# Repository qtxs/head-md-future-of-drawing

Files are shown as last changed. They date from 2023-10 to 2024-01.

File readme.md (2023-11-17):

# Work in progess. Future of drawing

John is a portatif assitant, a guide for beginer students on their artistic journey. He translates their daily movements into graphic poems, using the taken paths as the graphic layout. At the moments when user feels inspired and lost, John prints out a poem that aimed to trigger inspiration. I want to make young artists understand that very simple gestures, even mouvement is already an art from. Much like their artistic path and development, its the process that counts the most, not the final output. 

More stuff [here](/process/)

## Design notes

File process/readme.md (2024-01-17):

# Steps to build the thing 

07.12.2023

## Form
- 3D Modeling 
    - Case
        - Inside box for electronics
        - The main "pencil case" shape in two separate parts
        - Slider 

## Materials
- 3D Printing 
    - Box for electronics
    - The slider 
- Metal 
    - "Pencil case" part one - cut and bend
    - "Pencil case" part two - cut and bend
- Fasterners 
    - Probably couple of screws

## Electronics

- Arduino
    - Code
        - GPS tracker
        - Use gps data for text paths
        - Poem library
        - Light censor to trigger print
        - Thermal Printer control
    - Inputs
        - GPS
        - Light sensor
    - Output
        - Printer
- Dimensions
    - GPS tracker : (not including coin cell or holder):  
    - Printer : with seat 82 x 58 x 44mm / without seat 77 x 53 x 42mm
    - Light sensor: 40 x 16 x 7 mm
- Wiring 
    - What is connected to what 
- Power
    - Serie of lipos 
        - 100.5 x 48.5 x 18mm
        - 5V 3A / 3V 1A

##

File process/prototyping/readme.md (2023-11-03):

# Prototyping. Work in progesss.

The departure point for those prototypes was an idea of creating a portable ai assistant that would capture mouvements, gps paths and other stuff (to define still but probs weather too) and translate them into a visual poem. I aim to create an annoying assitant that would capture the lack of mouvement and on that point it would print out a ticket saying that it's time to get shit done. The paths made by the user before he/she sits for too long, are used as paths for the printed poems.

So while making those prototypes, I tried out three variants, depending on its portability and possible interactions. I should also mention that as my goal is to translate common daily rituals/mouvements all types of interactions are not direct so I didn't find it convinient to test the interaction part on other people.

So there are my observations:

# Prototype 1

Prototype 01 was inspired by my portable iphone case. I often use it myself for writing down my random thoughts during the day etc.

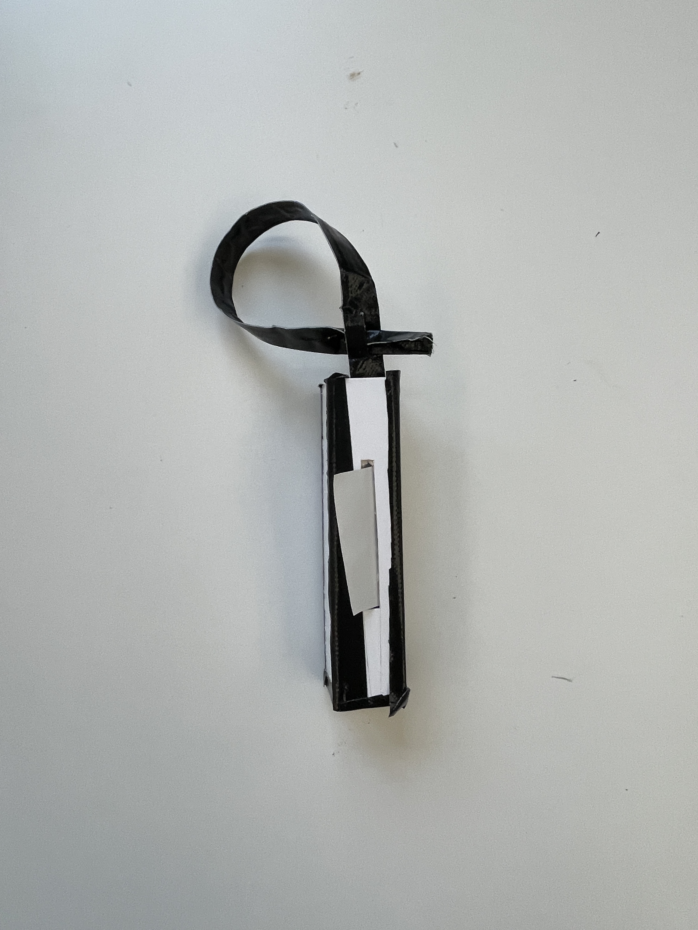
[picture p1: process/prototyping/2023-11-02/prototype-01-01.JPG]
Reference Image

Reference Image

## -
    As I want to integrate a small printer inside of it, it's going to be way too heavy
    Annoying object on the hand
    Not so pratical 
    Not so pretty 

## +
    Possible to integrate other sensors like body temeorature, hand lifting, haertbeat frequency

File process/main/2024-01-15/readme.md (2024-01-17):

# Electronics

15.01.2024

I didn't manage to make my old code workable. So I prepared a serie of [bitmaps](/process/main/2024-01-15/Bitmaps/poems//) compositions that I made, using the haikus that I generated with chat gpt. The went out pretty well but I still encountered some issues with color intensity. I guess it's just the heating issues as with each print it became darker.
[Refence Image](/process/main/2024-01-15/20240115_Print0.jpeg)
[Refence Image](/process/main/2024-01-15/20240115_Print1.jpeg)
[Refence Image](/process/main/2024-01-15/20240115_Print2.jpeg)
[Refence Image](/process/main/2024-01-15/20240115_Print3.jpeg)
[Refence Image](/process/main/2024-01-15/20240115_Print4.jpeg)

Wasn't expecting that bitmaps would require so much memory, so for the demo I can only use one of them. I wanted to print a random one each time it's on, but it's to big. It was also the biggest size that I found 384x550 px and it still looks small though.

The rest of the day I spent on the final [documentation](/process/presentations/20241112_HEAD-MD1_Caran-d-Ache_Ekaterina-Bliznyuk_John.pdf) and made some nice rendredings:
[Reference Image](/process/main/2024-01-15/side01.png)
[Reference Image](/process/main/2024-01-15/front01.png)
[Reference Image](/process/main/2024-01-15/front03.png)

I also found this [thing](/process/main/2024-01-15/2.stl) on web, to use as a clipper for my prints.

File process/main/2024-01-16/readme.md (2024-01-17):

# Finalising

16.01.2024

By today everything was 99% ready. Just needed to polish the rest of objects, put them together, make cable management, try out demo etc.
[!Reference Image](/process/main/2024-01-16/20240116_Nerding.JPG)

I also printed out a cover for the hole that I had to make on my printer.
[!Reference Image](/process/main/2024-01-16/20240116_CoverFront.png)
[!Reference Image](/process/main/2024-01-16/20240116_CoverBack.png)

I also made some slight adjustements on my [code](/process/electronics/printer/Final/FinalCode/FinalCode.ino)
The final of my [fusion](/process/main/2024-01-16/Ekaterina_Bliznyuk_Final.f3d)

I had some free time afterwards, so I made [slides](/process/presentations/20241712_Slides.pdf) for the jury presenation.

So I guess this is the end. Was a cool project, thank you!

[!Reference Image](/process/main/2024-01-16/20240116_ThankYou.gif)

P.S. would like to know how it goes the grade goes with abscences. I know I had a lot of them but they are all suppossed to be justified (or at least 80%).

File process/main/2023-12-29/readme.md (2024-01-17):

# Electronics

29.12.2023

Testing out printer.
[code](/process/electronics/printer/)

There is the [docuement](/process/main/2023-12-29/CommandsSet.pdf) I was using, found in DFRobot. Test pics are [here](/process/main/2023-12-29/)

 Different layots, type rotation etc. For now I just added a random number to define the printing left margin, but with gps I will map those values. Images of tests are in the folder. Goig out pretty well, need to decide which one I prefere esthetically and which works the most with gps data.

 Still need to change the font, which will be more tricky as I need to convert each character to bitmap image and associate it to the letters. Seems doable.

 Next steps:

1. Change font
2. Make list of poems to randomly compose them
3. Use gps data
4. Finish 3d model and print it at home

Here are the correct schemes of my connections.
[!Reference Image](/process/main/2023-12-29/20231229_Scheme01.png)
[!Reference Image](/process/main/2023-12-29/20231229_Scheme02.png)

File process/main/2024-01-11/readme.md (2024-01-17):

# Form

 11.12.2024

Went back to Xavier with the all the pieces. He was quite unhappy as I actually did it wrong and print supports in PLA and not carbon, they were too empty and not restant enough. But it still somehow worked #feelingblessed.

All other part of the day was working on [documentation](/process/presentations/20241112_HEAD-MD1_Caran-d-Ache_Ekaterina-Bliznyuk_John.pdf).

Sadly tho, because I had some questions to Piere but he wasn't here.

Fun fact, any of my electronics haven't arrived yet. Hopping for tomorrow as it will infleunce a lot my demo.

Next steps:

1. Polish metal
2. Print second part
3. Improve code
4. Get that printer

How polishing goes so far:

[Reference Image](/process/main/2024-12-11/20241211_Polishing.JPG)

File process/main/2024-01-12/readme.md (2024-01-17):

# Form

 12.12.2024

 Putting the portable part to print. 14H of printing. Sounds ok. Just in case if it's not clear what I mean by portable:
 [Reference Image](/process/main/2024-12-12/20241212_Portable.png)

 Highlights of the day:

 1. Printer arrived
 2. Printer doesn't fit in the printed part.

 Don't know what happened, nut I guess I just suck at maths. Ok. Need to think of a solution and time management as it's still 23H for the print.

 # Electronics

 Got back to code at the end of the day. Found some connection troubles and took way too long to solve it. My brain is compatible with code only in the morning.

 Next steps:
 
1. Find solution for the reprinting
2. Resolve code
3. Pick up print

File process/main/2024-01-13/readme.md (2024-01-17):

# Form

13.01.2023

Found a solution for the printer fitting. A bit yolo but works.
[Reference Image](/process/main/2024-01-13/20240113_Solution0.png)
[Reference Image](/process/main/2024-01-13/20240113_Solution01.png)
 Yes I just made a huge whole on it's back. But it was the only solution I could find on the moment. I know that it may look ugly but thanks to my paper hokder on the back, it should be hidden.

# Electronics

Cool surprise. Any of the code that I wrote for the other printer, works on this one. The other one was also adafruit but just the previous model, so I really don't know what's the issue. It basically prints out code (wtf). So I have a choice now, either I try to find how to correct it, either I prepare bitmaps and make it a bit more graphic design looking. Have the week end to do it.

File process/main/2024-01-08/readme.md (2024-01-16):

# Form

08.12.2024

Last week. Main focus on the product making. After discussion with Laure today, had some minor adjustements on the model. Put it to print when I got home.
23H of printing, hoping that dimension are ok. All files are in this folder.
[Reference Image](/process/main/2024-12-08/20241208_Print0.JPG)
[Reference Image](/process/main/2024-12-08/20241208_Print01.JPG)
[Reference Image](/process/main/2024-12-08/20241208_Print02.JPG)
Had to reprint it like 3 times at the begining, as my printer's bed wasn't adjusted correctly enough. But I fixed the issue and am feeling proud.

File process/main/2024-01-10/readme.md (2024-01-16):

# Form

10.12.2024

Had a metal workshop appointment todday. [This](/process/main/2024-12-10/20241210_Dimensions.pdf) was the document for Xavier.
Due to technical requirements of the bending machine, I had to sligtly change the shape of the holding metal part. Just change its radius basically.
[Reference Image](/process/main/2024-12-10/20241210_ShapeOld.png)
[Reference Image](/process/main/2024-12-10/20241210_ShapeNew.png)
The other thing Xavier told me is how it should be screwed correctly, so I made those additional supports that I will print ASAP and get back to Xavier on Thursday.
[Reference Image](/process/main/2024-12-10/20241210_Supports0.png)
[Reference Image](/process/main/2024-12-10/20241210_Supports01.png)
[Reference Image](/process/main/2024-12-10/20241210_Supports02.png)

Then I went to Fred so he could cut all the metal sheats. Everything was done but one of the holes wasn't big enough to include the metal sheat inside, so I had to file it a bit. 
When I got home, the model was ready and it printed out very well actually. So the overall look on the moment is this guy:

[Reference Image](/process/main/2024-12-10/20241210_Him.JPG)

Next steps:

1. Print the second/portable part
2. Polish both
3. Correct code
4. Make dat baby work
5. Documentation v1

(May be a different order)

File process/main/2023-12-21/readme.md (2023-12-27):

# Finalising

After talking with Laure, she gave me some new and very cool [references](/process/prototyping/2023-12-21/20231221_NewRefs/)

New sketches for object:

[!Reference Image](/process/prototyping/2023-12-21/20231221_Sketches01.png)
[!Reference Image](/process/prototyping/2023-12-21/20231221_Sketches02.png)
[!Reference Image](/process/prototyping/2023-12-21/20231221_Sketches03.png)

So I am starting over my 3d model from those skectes and references. It evolved into something more concrete, not a pencil case anymore but a home station/organiser with several objects.

Despite abscence of electronics that were ordered, I managed to find a therma printer at least, so I can start codeing and testinf stuff. #wip

To do during holidays:

- Finish 3D model
- Print 3D model
- Understand how thermal printer works
- Make thermal printer work
- Get lit

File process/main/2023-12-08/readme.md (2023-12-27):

# Form

08.12.2023

After the last discussion with Laure about the shape and Pierre about the quantity and dimensions of electronics, I've taken the descision to make two separated boxes: one for electronics and one as the cover. It was also influenced by the possibilites of atelier metal as Xavier told me that machine couldn't do the fold the metal the way I wanted first. I stll have more questions to ask him, but I think it's more relevant to have a clear idea(s) of how I want it to look.
So I started sketching out possibile versions in fusion 360.

[!Reference Image](/process/prototyping/2023-12-08/20231208_Boxes.png)
[!Reference Image](/process/prototyping/2023-12-08/20231208_Boxes2.png)
[!Reference Image](/process/prototyping/2023-12-08/20231208_Boxes3.png)
[!Reference Image](/process/prototyping/2023-12-08/20231208_Boxes4.png)
[!Reference Image](/process/prototyping/2023-12-08/20231208_Boxes5.png)
[!Reference Image](/process/prototyping/2023-12-08/20231208_Boxes6.png)

# Electronics

All the required electronics:

1. Thermal printer
https://www.bastelgarage.ch/dfrobot-embedded-thermal-printer-ttl-serial?search=printer

2. GPS Tracker
https://www.adafruit.com/product/5440

3. Lithium battery in serie
https://www.bastelgarage.ch/2x18650-lithium-batterie-shield-5v-3a-3v-1a?search=18650

4. Light sensor
Already in the kit

5. Accelometer
https://www.digitec.ch/en/s1/product/purecrea-mpu-6050-3-axis-accelerometer-with-gyroscope-development-boards-kits-36359715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

This last one was added probably too late, but it is something that will be needed for the exposition. As the main idea of my assistant is to be portable and to record daily gps, it is quite impossible to do so in the context of exhibition. So I sligtly adapted the project and though of its scenogarphy for the exhibition.

I want to attach the assistant to the ceeling so it suspends and people can come and interact with it by pushing it so it swings only in two axis. That's why I need accelometer here, it will basically replace the gps tracker. Recorded mouvements from it's mouvements will be used as the poetry layout. It also allows to make it a bit bigger, so I can actually double the carandache pencil box dimensions.

Next steps:

1. Discuss this idea with teachers (electronics, scenography, shape...)
2. Conceptualise more the poetry itself(what words, why, how)
3. Take a descision for the final shape

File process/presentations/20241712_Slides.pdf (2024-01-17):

JO
H
N

# ready-made poetry

EKATERINA BLIZNYUK
«JOHN»

17.12.2024 HEAD MMD1

«John» accompanies young artists daily to stimulate their

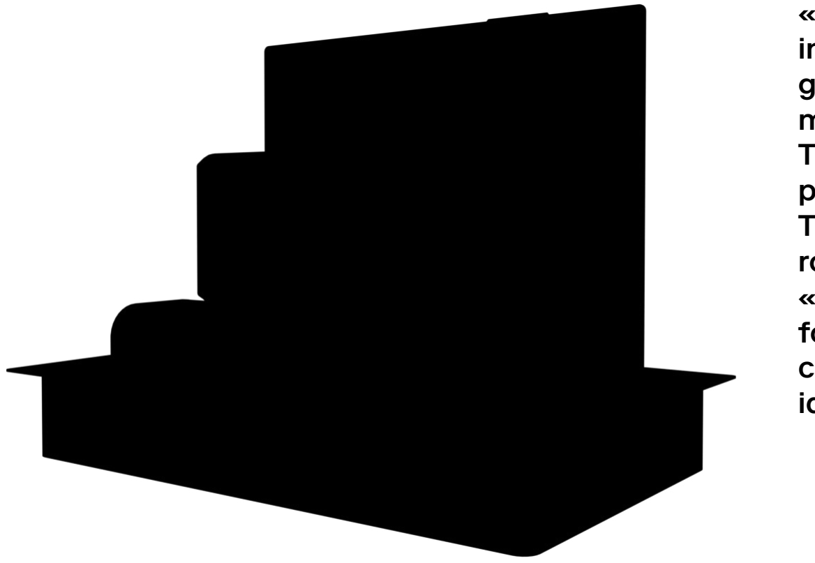
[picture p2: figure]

inspiration through their own mobility. His aim is to show beginer creators that their daily paths can evolve into something creative, much like their artistic journeys.
The AI records GPS movements, translating them into a graphic poem that reflects the journey’s layout and visited areas. This poetry encourages artists to find inspiration in their surroundings.
«John» features a two-part design, a portable component for daily use and a stationary home station with a printer, creating a comprehensive setup for organizing creative ideas.

### what is it

# PART 1

### what is it

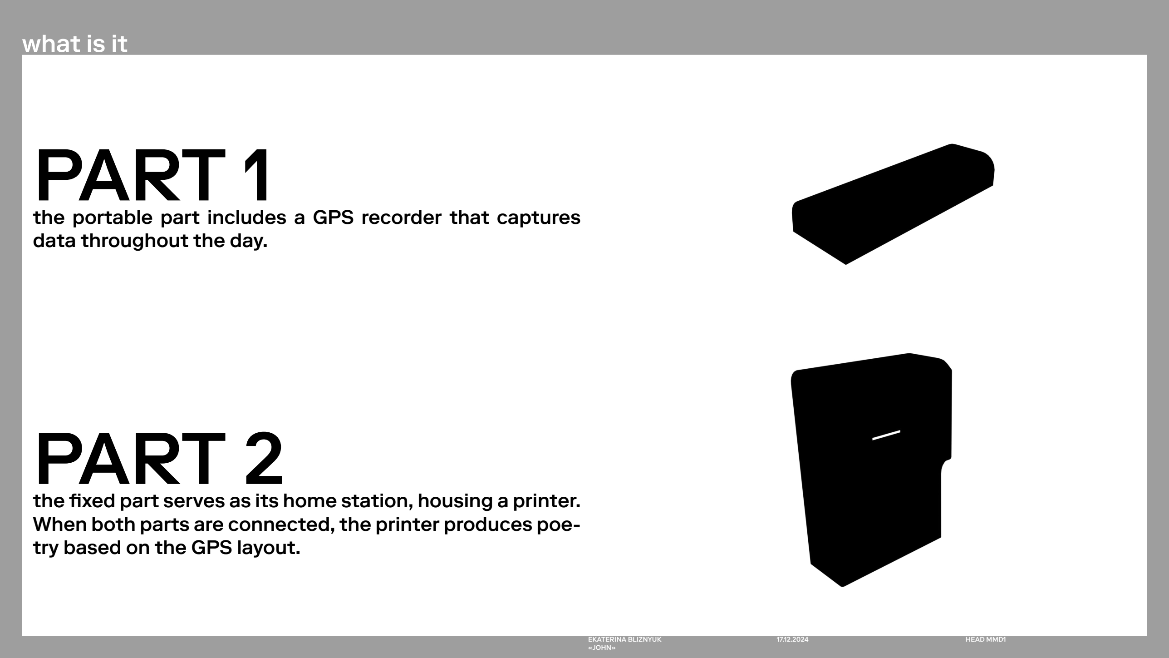
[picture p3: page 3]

the portable part includes a GPS recorder that captures data throughout the day.

# PART 2

the fixed part serves as its home station, housing a printer. When both parts are connected, the printer produces poetry based on the GPS layout.

### how it works

1

user caries John during the day
2

GPS data consistently records
3

back home, user puts john to the station
4

printer produces a poem, artist gest inspired

### what is his goal

provides inspiration | improves creativity | encourages artists

helps to create

organises ideas

reminds to observe the surroundings

assists in debugging | prints cool poems

# DEMO

### please work

### where it comes from

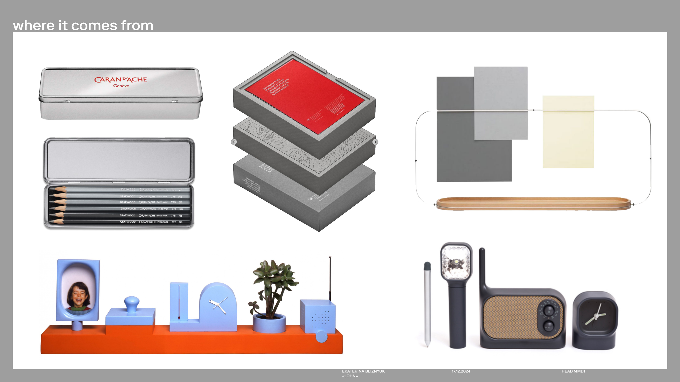
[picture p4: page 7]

### how it could be

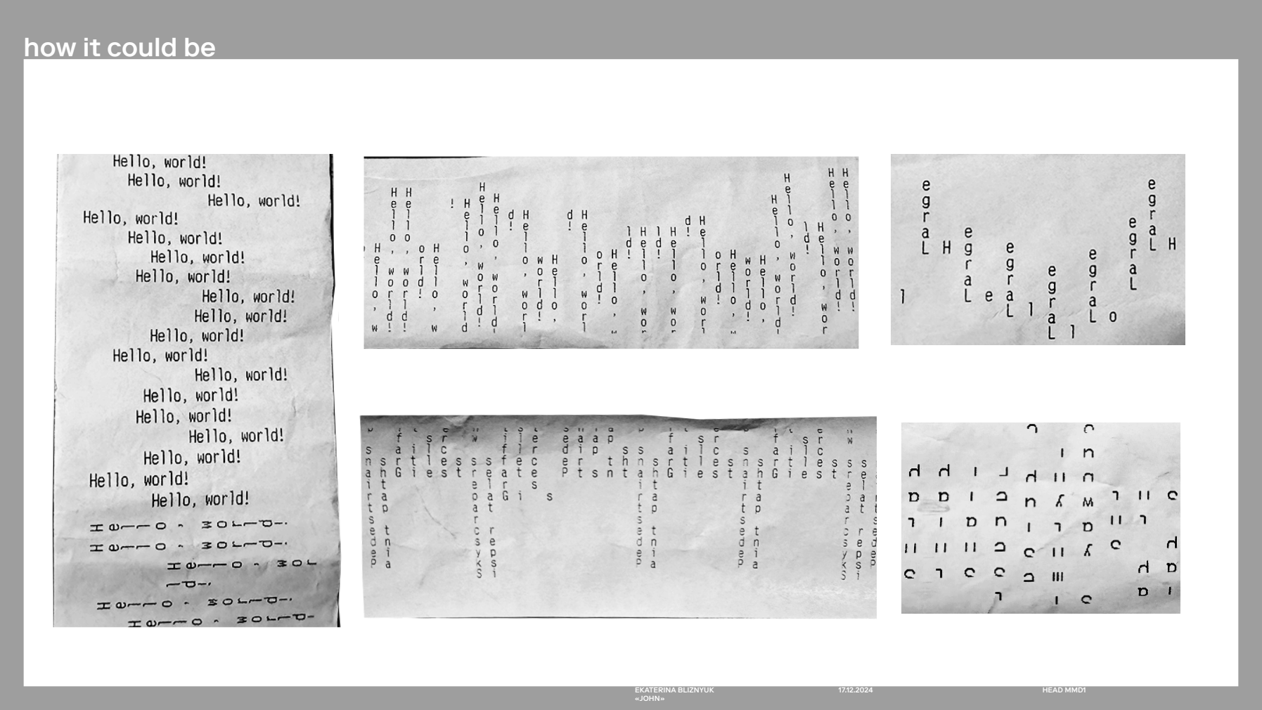
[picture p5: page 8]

### how it could be

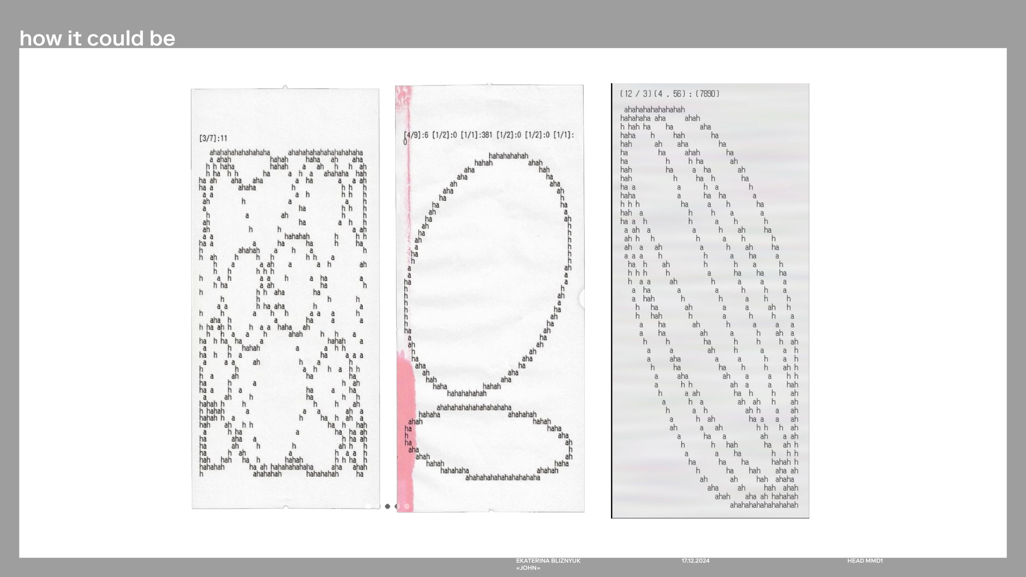
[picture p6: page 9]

### how it could be

weather = mood

country = language

location = meanings

number of steps... | .......

# TH Y O U

A
N K

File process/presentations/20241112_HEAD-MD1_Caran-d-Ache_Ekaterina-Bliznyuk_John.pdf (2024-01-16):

Master Media Design 1 | 17-01-2024
Caran d’Ache
Future of Drawing

# John

# ready-made poetry

Ekaterina Bliznyuk
John

# Project Description

«John» accompanies young artists on their daily and artistic journeys to stimulate their inspiration through their own mobility. His aim is to show beginer creators that their daily paths can evolve into something creative, much like their artistic journeys,where the developmental process itself is an art form. I aim to help them realize that simple gestures can be translated into something artistic, making them aware that they are creating without even knowing it.

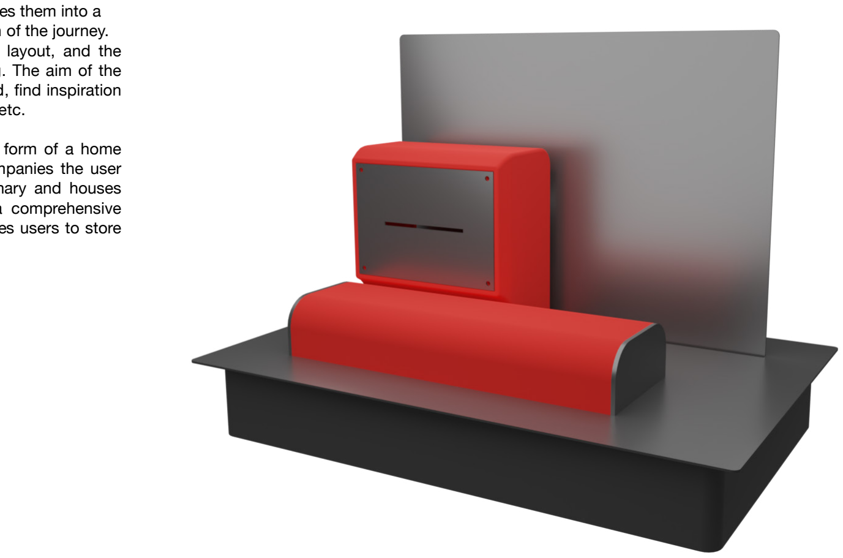
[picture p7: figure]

By recording GPS movements, the AI translates them into a graphic poem, forming a visual representation of the journey. The route taken by the user influences the layout, and the visited areas impacts on the poetry meaning. The aim of the poetry is also to remind artists to look around, find inspiration and beauty in surrounding them streets, cars etc.
Designed in two components, it adopts the form of a home working setup. The portable segment accompanies the user daily, while its home station remains stationary and houses a printer. The concept aims to establish a comprehensive working and creative environment that enables users to store and organize their ideas.

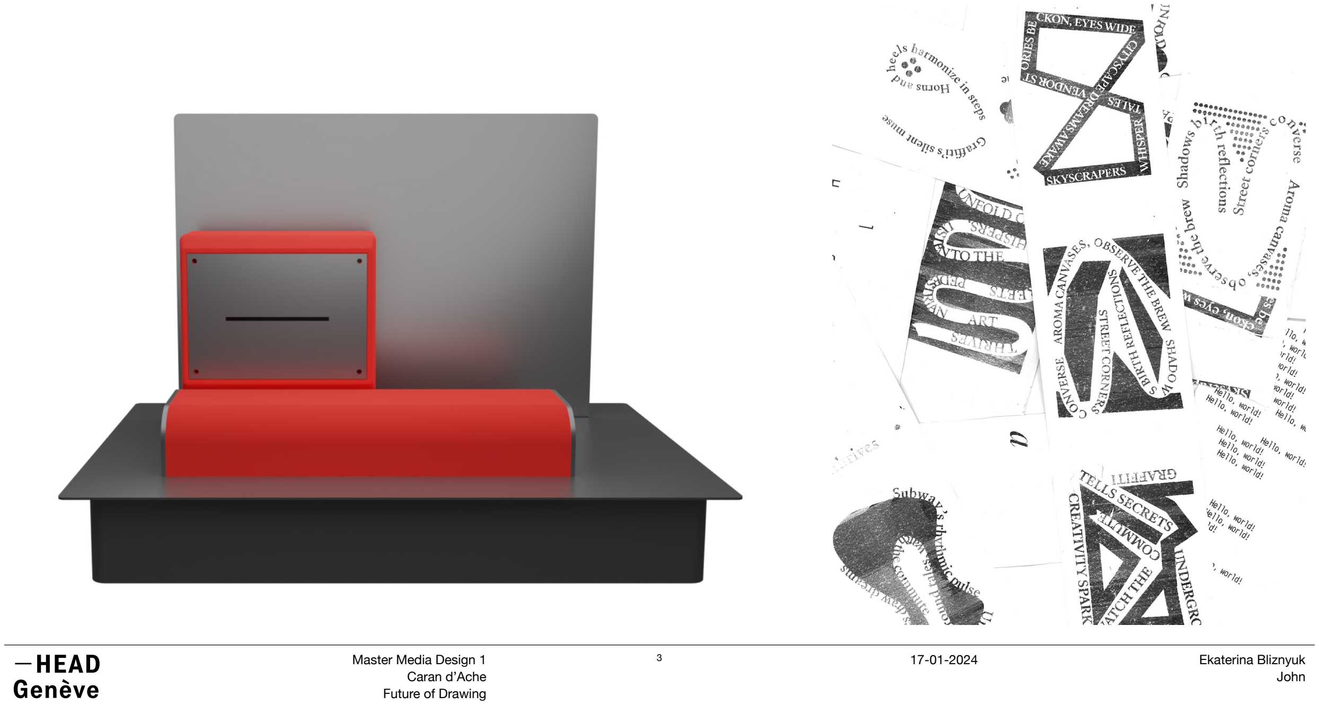
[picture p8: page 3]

# User Journey

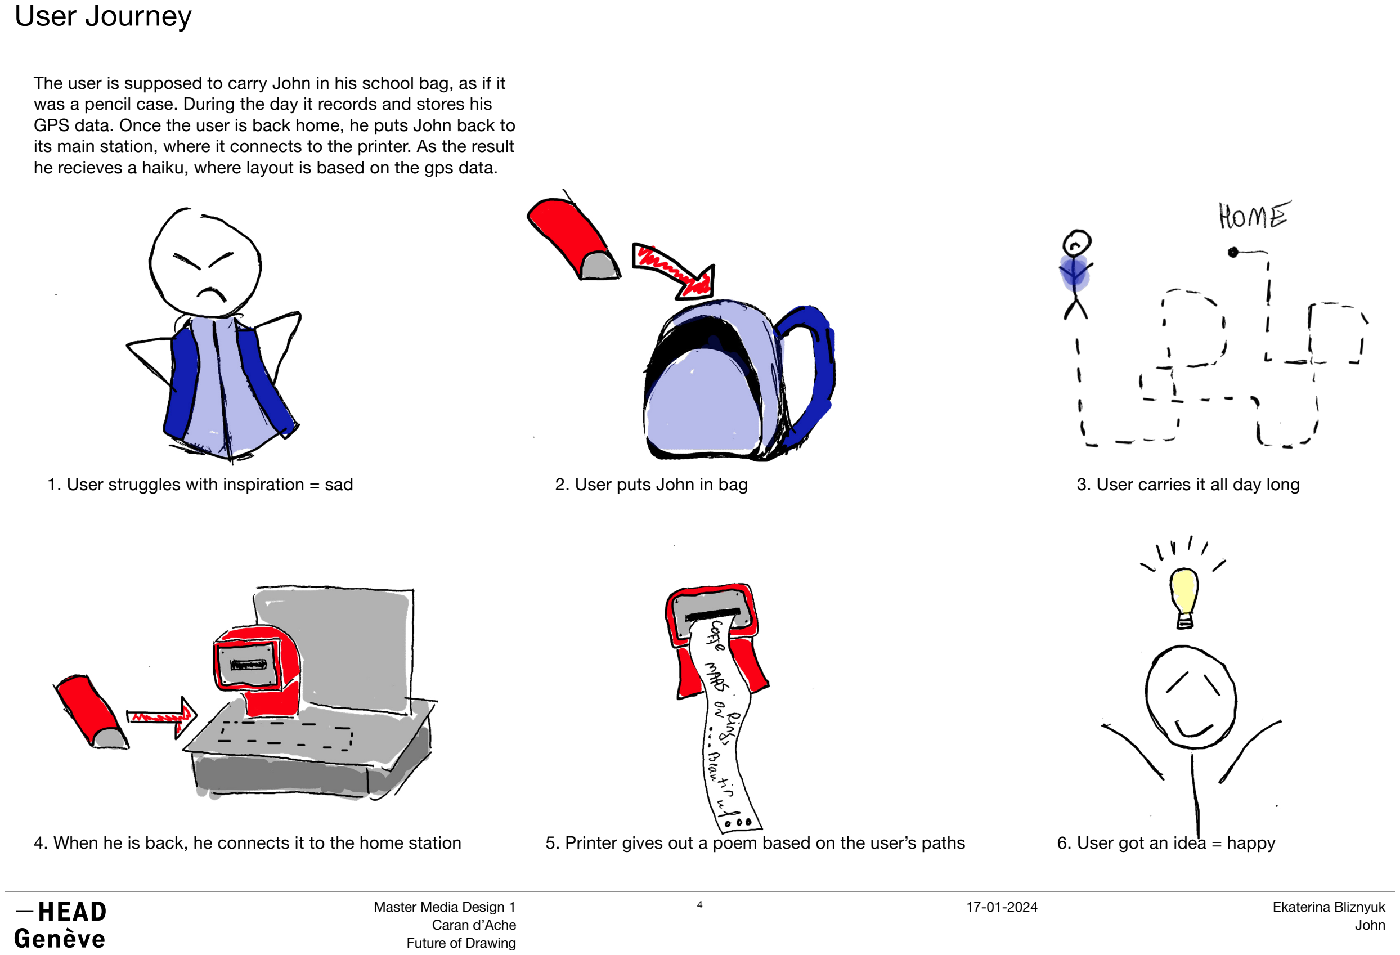
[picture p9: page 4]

The user is supposed to carry John in his school bag, as if it was a pencil case. During the day it records and stores his GPS data. Once the user is back home, he puts John back to its main station, where it connects to the printer. As the result he recieves a haiku, where layout is based on the gps data.

1. User struggles with inspiration = sad | 2. User puts John in bag
4. When he is back, he connects it to the home station | 5. Printer gives out a poem based on the user’s paths | 6. User got an idea = happy
3. User carries it all day long

# Field observations

All artists struggle to find inspiration. Sometimes all it takes is a word, a situation, a sound... Inspiration can also come at an unpredictable moment. Many of the little things that surround us in everyday life can be transformed into something artistic, and beginning artists are unaware of this.

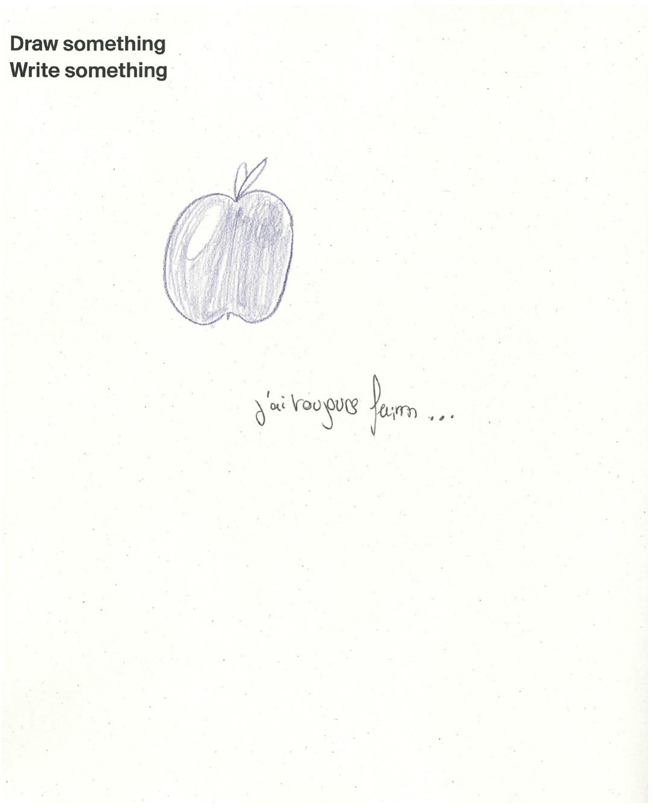
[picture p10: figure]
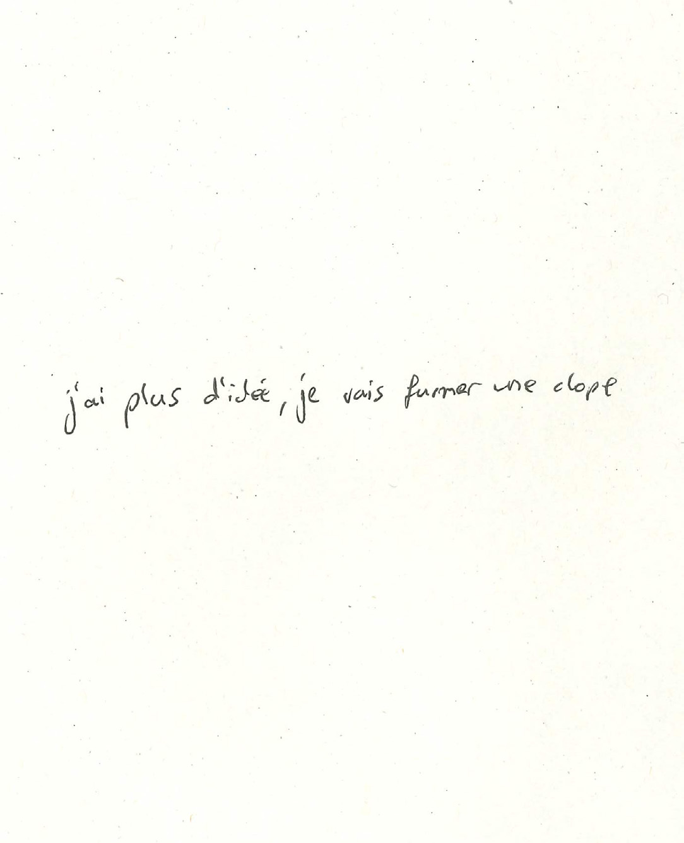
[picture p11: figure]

Have random events had an impact on your inspiration? Which ones?

A scooter accident, a downpour, a glass spilling on my computer... Just thinking about the fact
that nothing lasts

It happens that a random song pops in my playlist and inspire
me visuals or things

Sometimes I see random shit on fyp of instagram /tik Tok that make me think about my master thesis, like graphic choices

How often are you faced to those events in daily life?

Infinity! you just have
to take the time to look.

Up to twice or thrice on some days

At least 1

# Paper prototypes

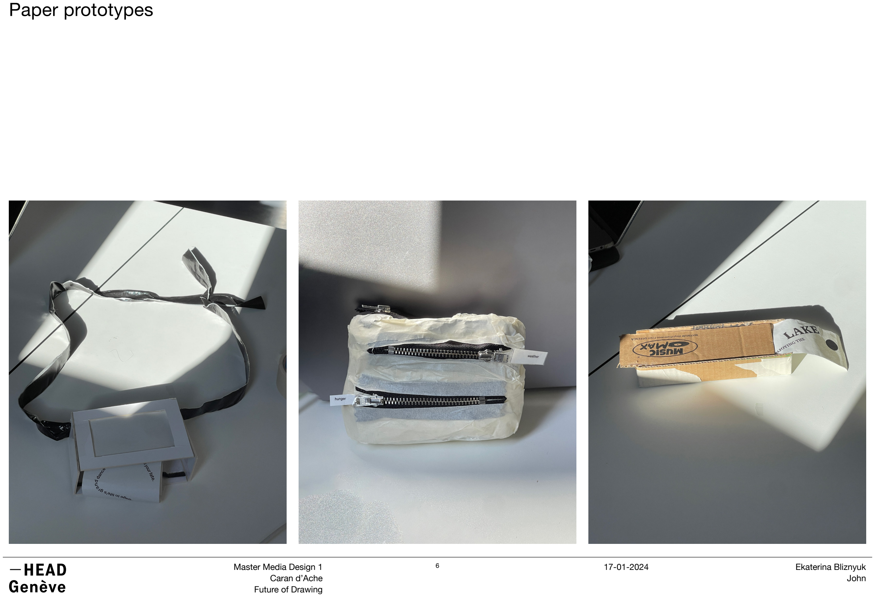
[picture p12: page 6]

# Shape research

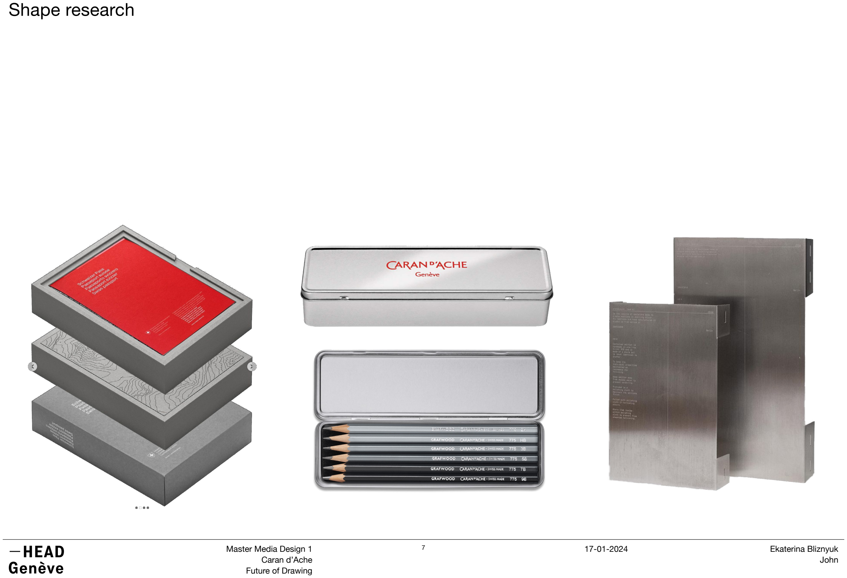
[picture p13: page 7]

# Shape research

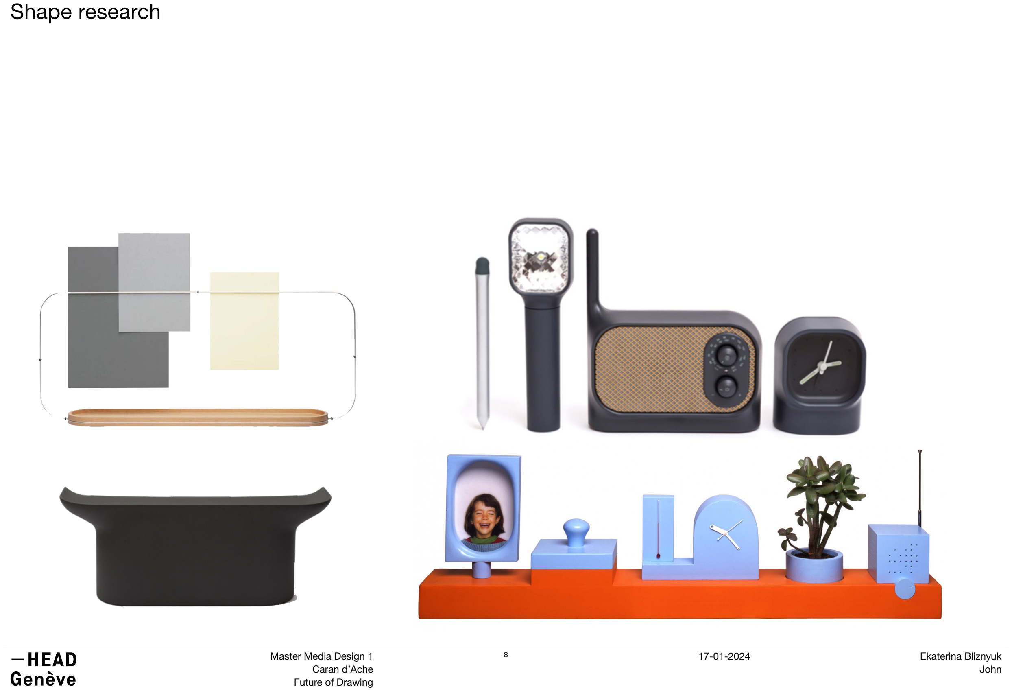
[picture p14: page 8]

# Shape research

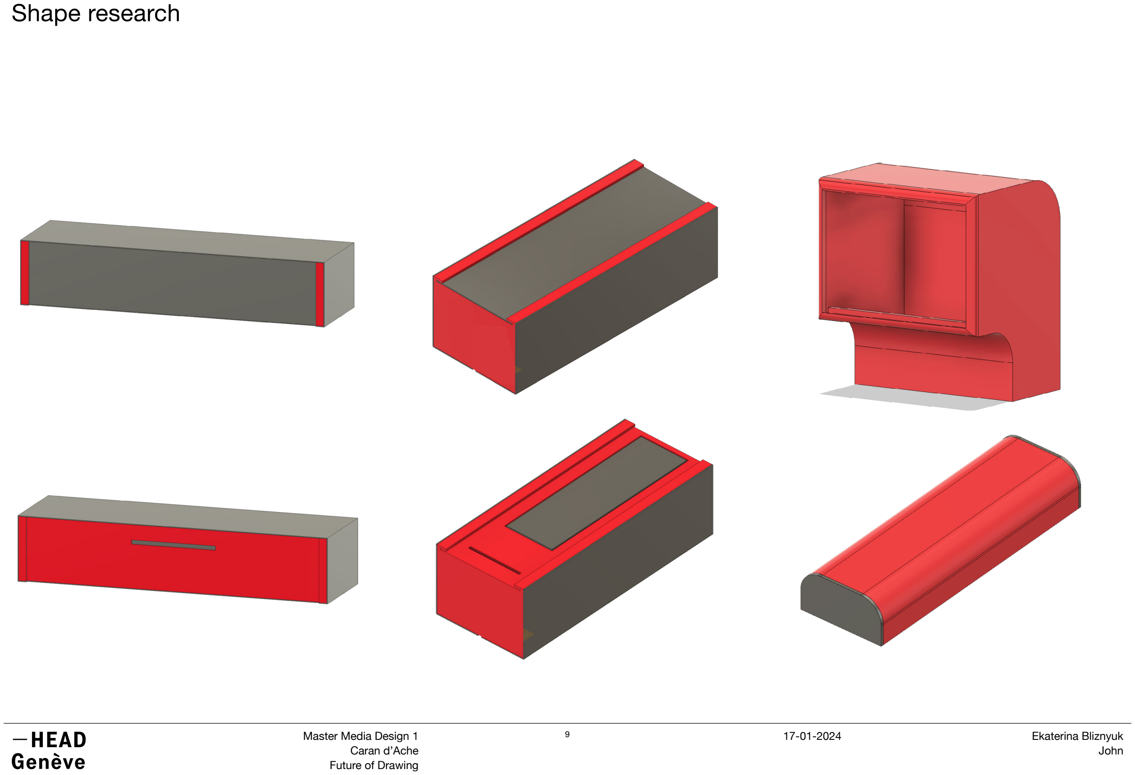
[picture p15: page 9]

# Electronics

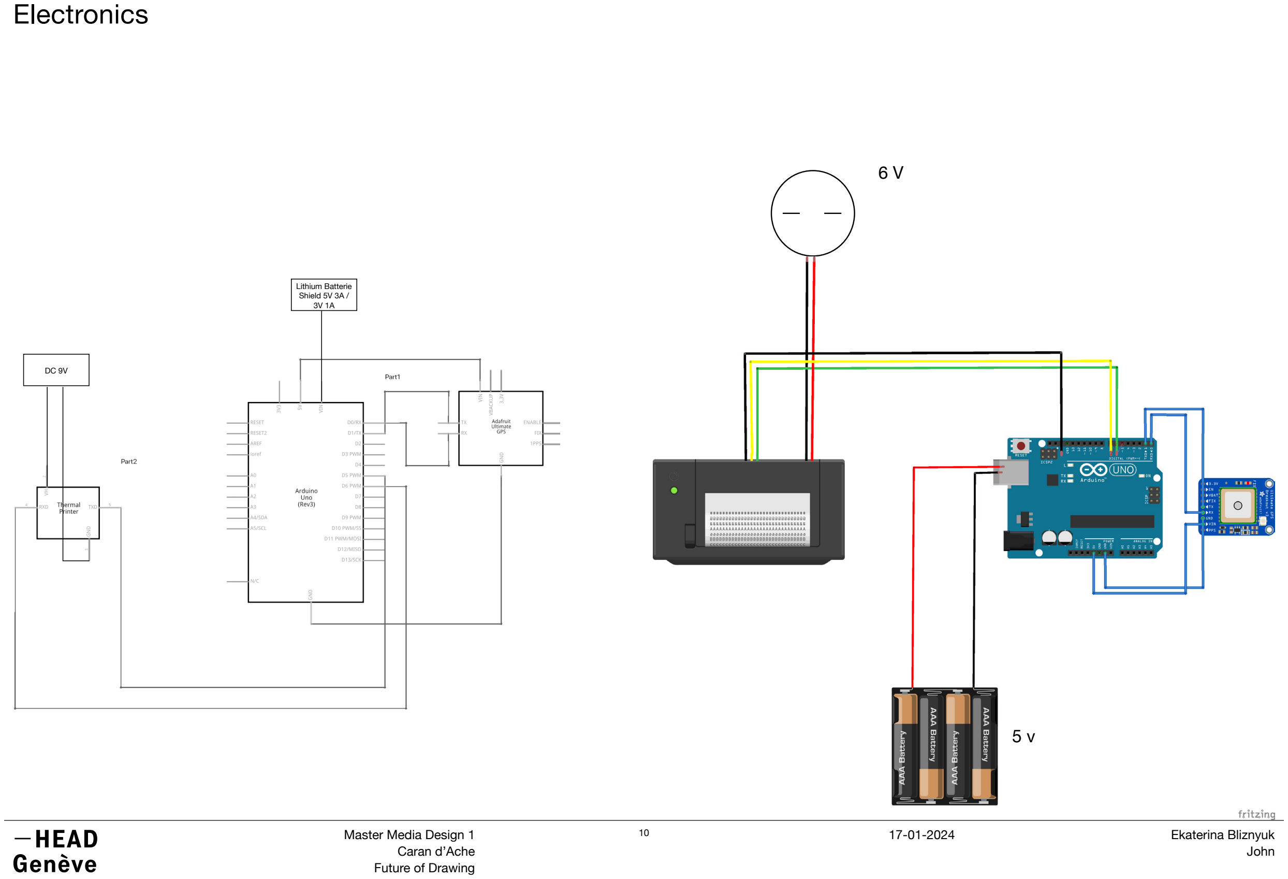
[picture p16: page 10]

6 V

5 v

DC 9V

Lithium Batterie
Shield 5V 3A /
3V 1A

# Plan Drawings: The set

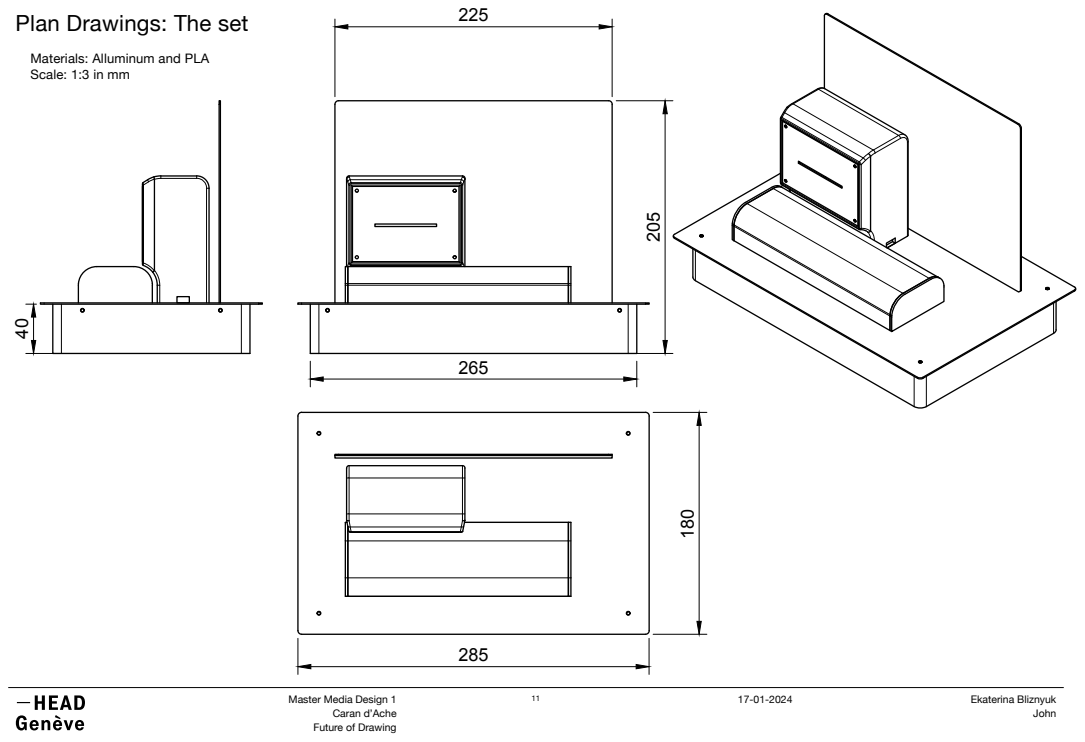
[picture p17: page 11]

Materials: Alluminum and PLA
Scale: 1:3 in mm

# Plan Drawings: Fixed Printer

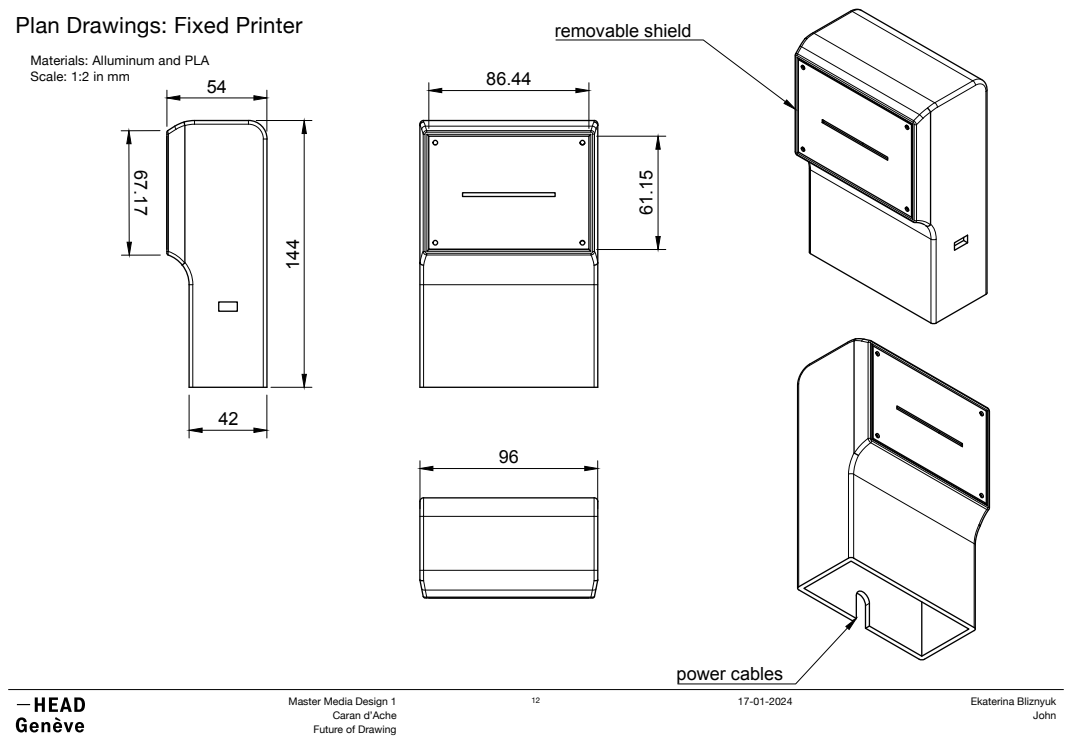
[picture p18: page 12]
power cables; removable shield

Materials: Alluminum and PLA
Scale: 1:2 in mm

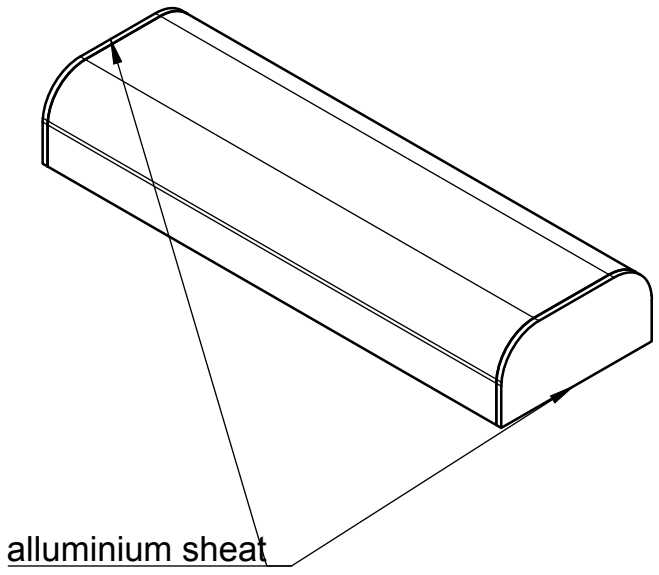
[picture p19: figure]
alluminium sheat

# Plan Drawings: Portable assistant

Materials: Alluminum and PLA
Scale: 1: 2 in mm

183

29.45

60

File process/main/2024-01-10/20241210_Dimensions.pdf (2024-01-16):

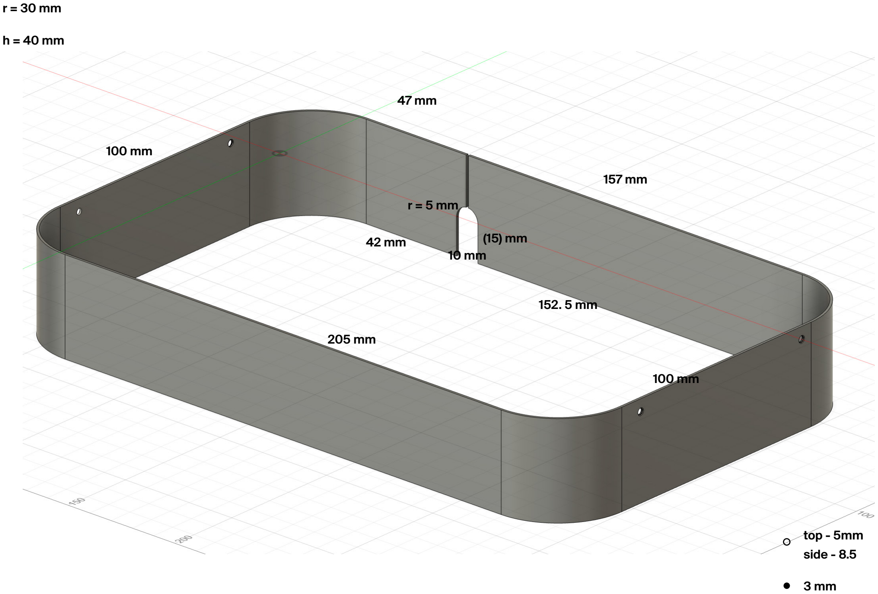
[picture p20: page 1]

r = 30 mm

h = 40 mm

r = 5 mm

### 47 mm

157 mm

100 mm

100 mm

205 mm

### 42 mm

152. 5 mm
(15) mm

### 10 mm

top - 5mm
side - 8.5

### 3 mm

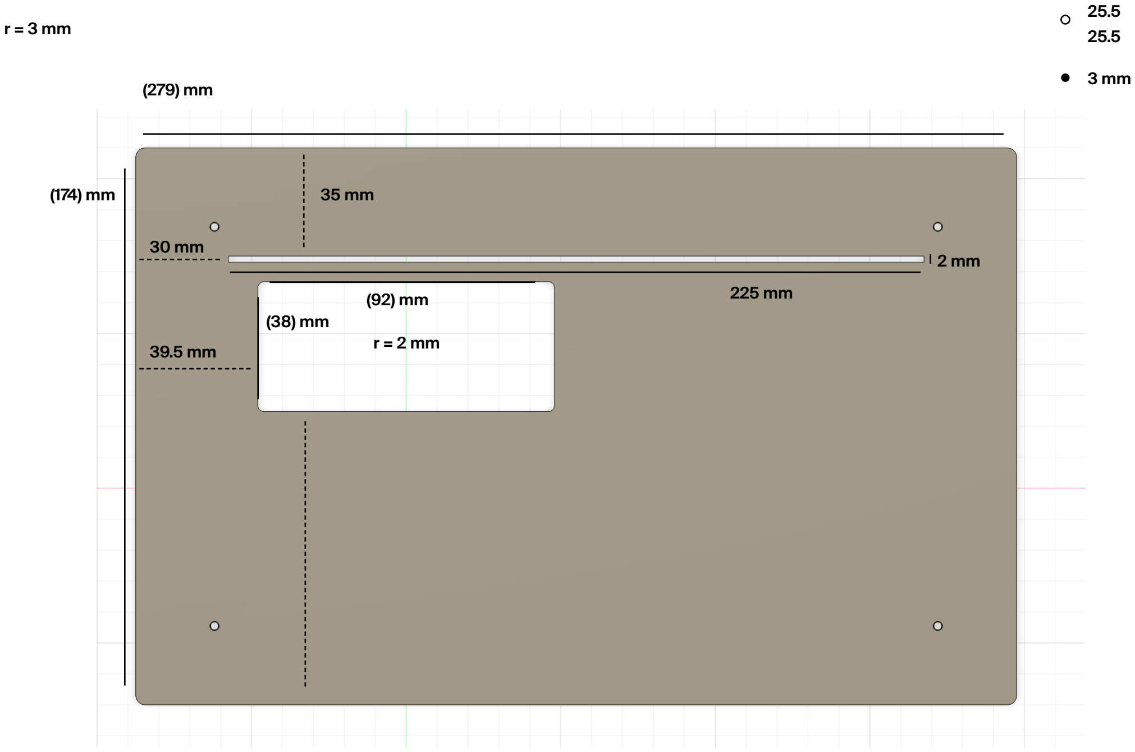
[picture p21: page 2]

(174) mm
(92) mm
(38) mm

225 mm

### 2 mm

### 39.5 mm

### 30 mm

### 35 mm

(279) mm

r = 3 mm

25.5
25.5

### 3 mm

r = 2 mm

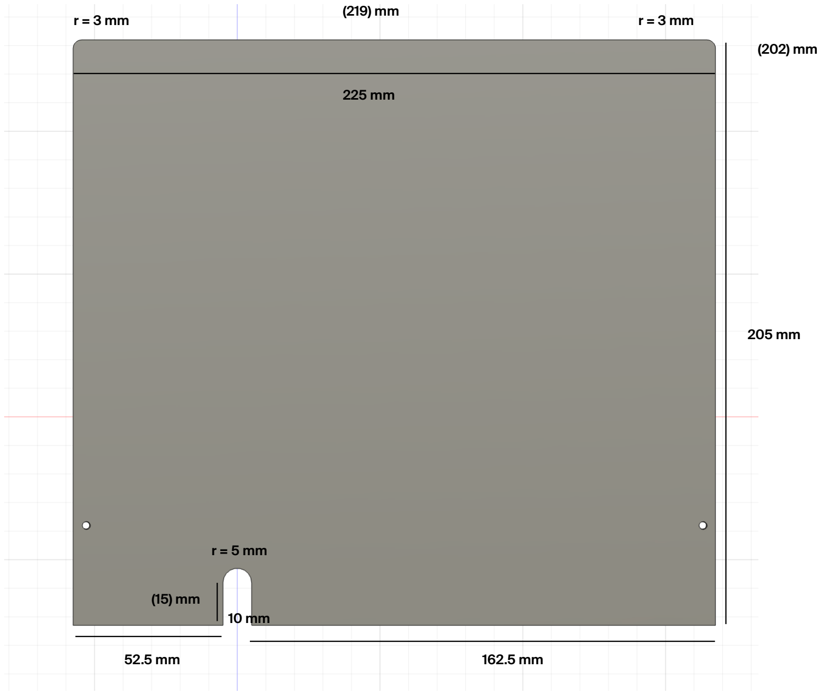
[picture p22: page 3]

r = 5 mm

r = 3 mm

205 mm

52.5 mm | 162.5 mm

### 10 mm

(15) mm

225 mm

(202) mm
(219) mm r = 3 mm

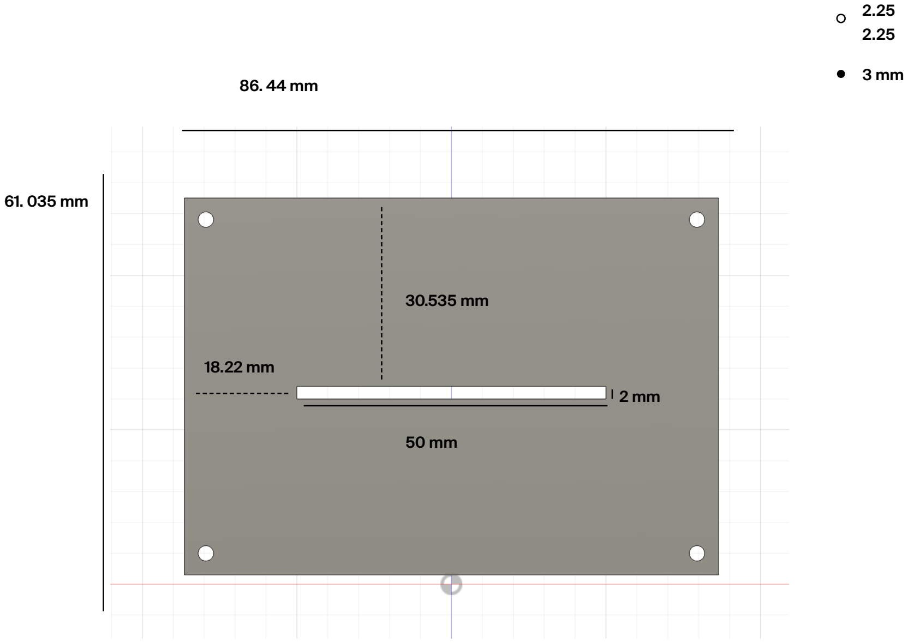
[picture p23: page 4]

61. 035 mm

### 18.22 mm

30.535 mm

### 50 mm

### 2 mm

86. 44 mm

2.25
2.25

### 3 mm

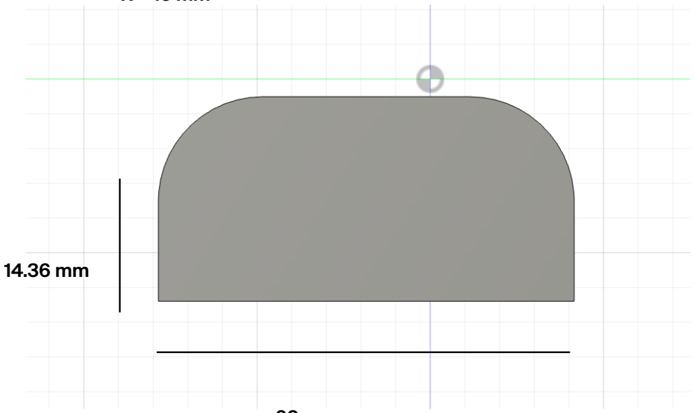
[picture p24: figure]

### 60 mm

R = 15 mm

x2

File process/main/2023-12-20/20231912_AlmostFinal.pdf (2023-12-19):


John Prototype

the assembly of all parts

### 1. Station

A. Inside Box (Printer_lipo)
B. Slider/Openner
C. Cover

### 2. Portable part

A. Outside Box (GPS+nfc tag?)

*need to rediscuss lots of stuff


1.A. Inside Box
3D Plastic

85mm

210 mm

### 65 mm

### 47 mm

### 50 mm

127 mm

### 25 mm

### 2 mm 2 mm 3 mm 1 mm


1.A. Inside Box
3D Plastic

printer goes here
for lipo i need to see it myself

### 44 mm

### 58 mm


1.B. Slider/Opener
1mm aluminuim sheat

210 mm

### 79 mm


1.C. Cover

*needs some screws but which?

210 mm

### 87 mm

### 69 mm


2.A. Outside Box (GPS+nfc tag?)

* need to redfine this one asap, confused about electronics

### 25 mm

150 mm

### 45 mm

gps+nfc goes here

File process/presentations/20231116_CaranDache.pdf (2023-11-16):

Ekaterina Bliznyuk
John
Master Media Design 1 | 16-11-2023
Caran d’Ache
Future of Drawing

# John

# Ready-made poetry

## Pitch

«John» accompanies young artists on their daily and artistic journeys to stimulate their inspiration through their own mobility.

His aim is to show beginer creators that their daily paths can evolve into something creative, much like their artistic journeys, where the developmental process itself is an art form. I aim to help them realize that simple gestures can be translated into something artistic, making them aware that they are creating without even knowing it.


By recording GPS movements, the AI translates them into a graphic poem, forming a visual representation of the journey. The route taken by the user influences the layout, and the AI randomly intervenes on the poem to give it a more unpredictable visual.

This portable assistant will then guide the young artists by providing inspiration at unpredictable moments throughout the day, encouraging an evolving creative process.


## User Journey or Scenario


1. User carries «John» in his school bag
2. When sitting for a long time,
he decides that he needs an inspiration
3. He takes out «John» from the bag
4. He opens it and recives a poetry, based on his path
5. Users gets inspired

## Field observations & Key Insights


1.While creating, it can be challenging to find inspiration without any context, and sometimes this context needs to be visual.

2.Some artists don’t fully realize that their very simple thoughts can emerge in art. It feels like a lack of confidence.

3.Lots of people encounter random things during the day. Those things sometimes trigger inspiration.

## Shape research & development


My inspiration object is a pencil case.
As a symbol of any creative beginings and uncoutable number of ideas.

## Visual and Material Moodboard


## Paper Prototypes


# Thank you

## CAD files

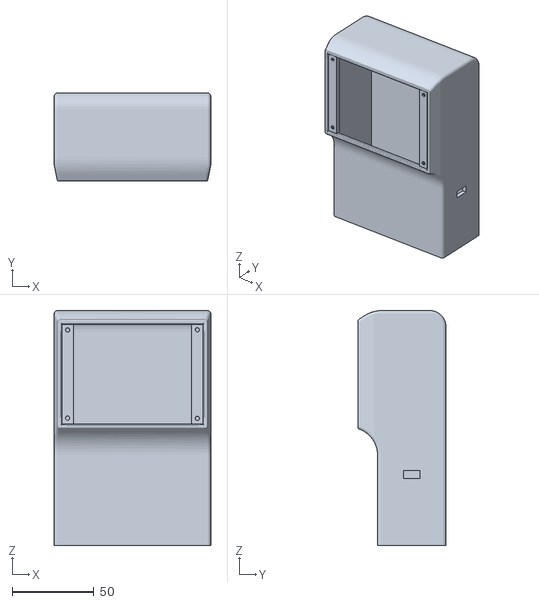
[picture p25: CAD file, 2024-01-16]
process/main/2024-01-08/fixed_03.stl
96.0 x 54.0 x 144.0

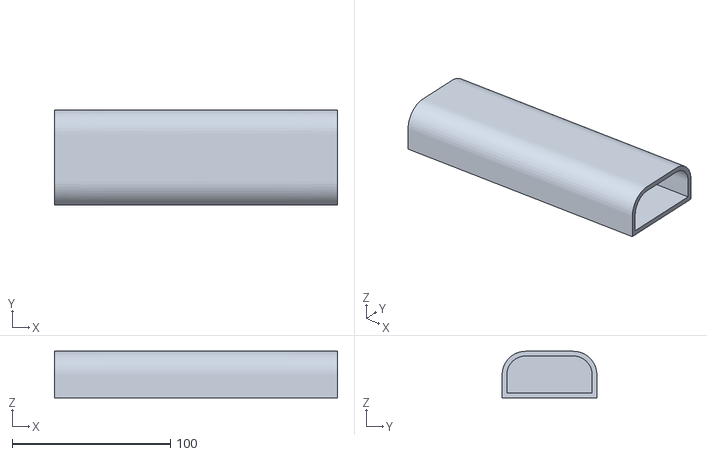
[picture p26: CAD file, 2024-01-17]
process/main/2024-01-12/portable_01.stl
179.0 x 60.0 x 29.4

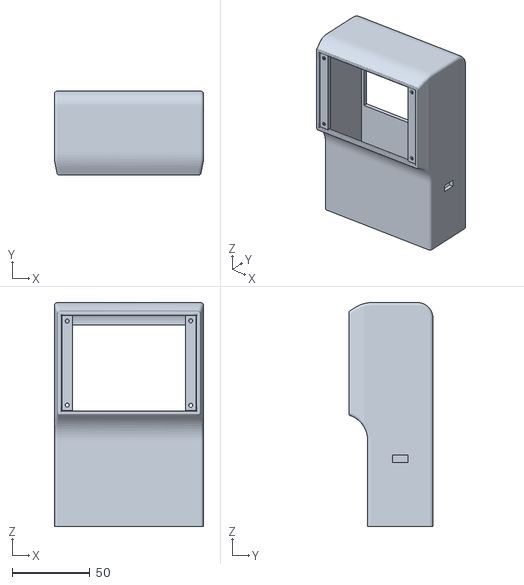
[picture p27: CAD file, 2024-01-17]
process/main/2024-01-13/fixed new.stl
96.0 x 54.0 x 144.0

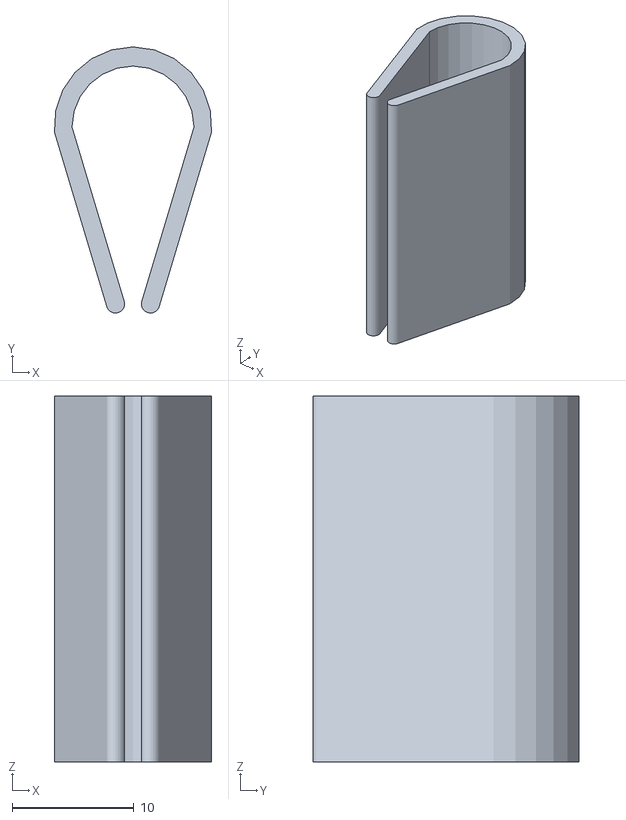
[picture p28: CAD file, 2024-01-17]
process/main/2024-01-15/2.stl
12.9 x 21.8 x 30.0

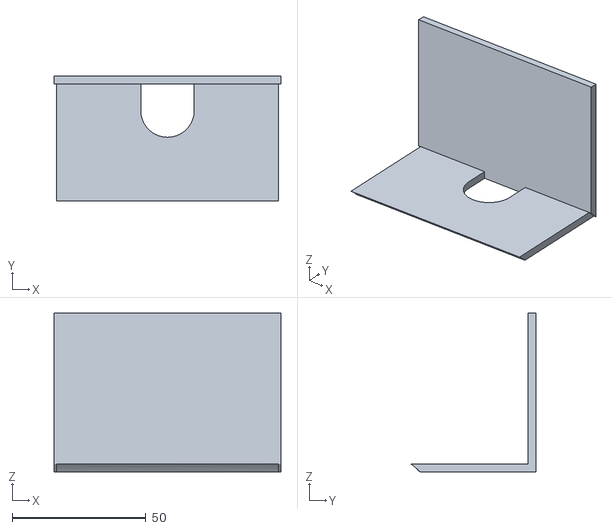
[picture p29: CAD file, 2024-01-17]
process/main/2024-01-16/20240116_Cover.stl
85.0 x 46.9 x 59.5

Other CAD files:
process/main/2023-12-20/John_AlmostFinal.f3d
process/main/2024-01-08/20240801_TheSet.f3d
process/main/2024-01-08/fixed_03.f3d
process/main/2024-01-16/Ekaterina_Bliznyuk_Final.f3d

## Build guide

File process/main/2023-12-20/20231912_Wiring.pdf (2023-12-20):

printer | arduino | gps sensor

plugged

Station | Portable

lippos

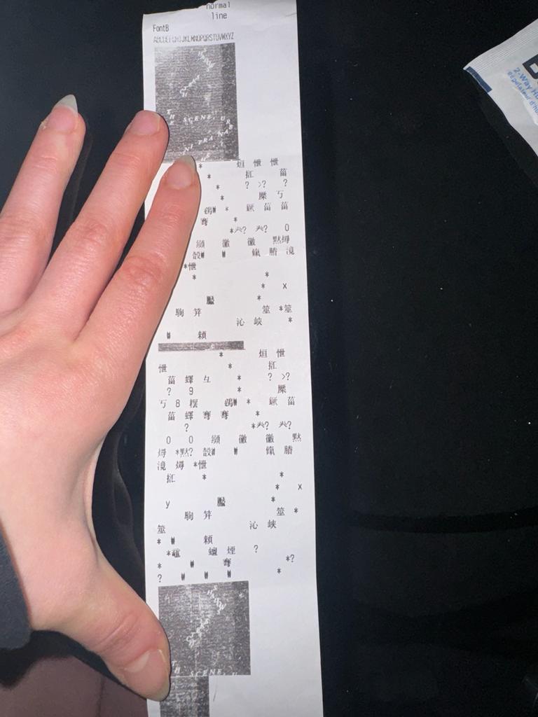
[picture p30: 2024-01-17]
process/main/2024-01-15/20240115_Print4.jpeg

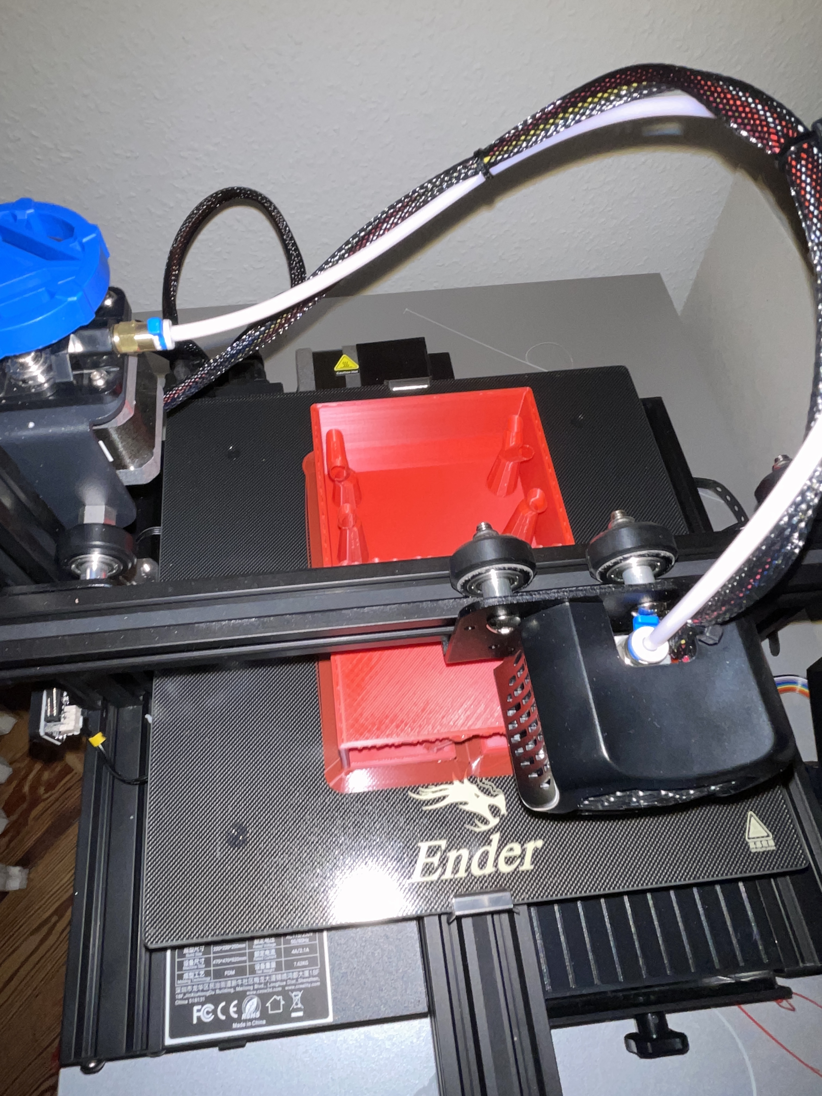
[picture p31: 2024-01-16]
process/main/2024-01-08/20241208_Print1.JPG

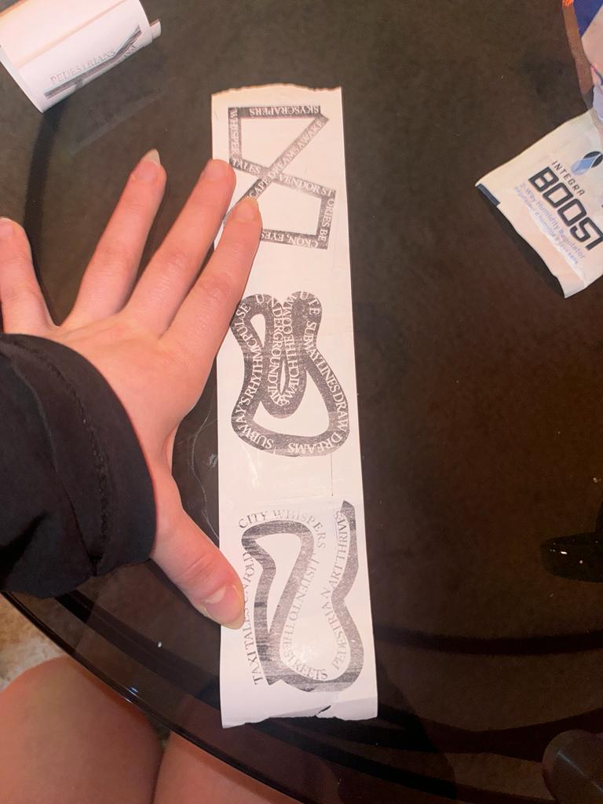
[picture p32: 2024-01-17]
process/main/2024-01-15/20240115_Print2.jpeg

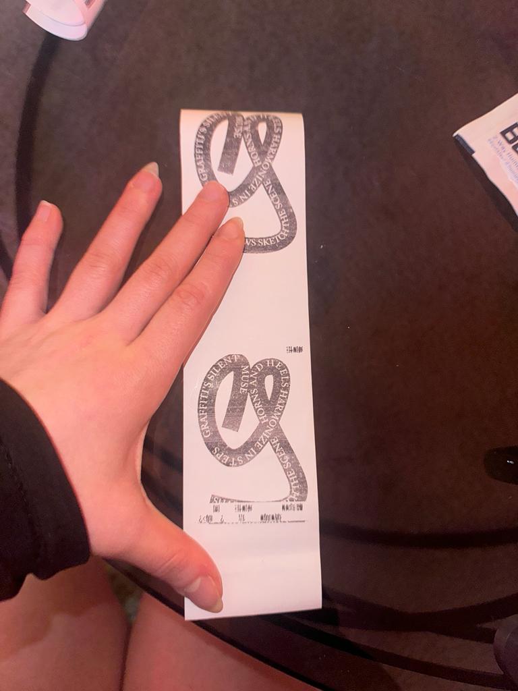
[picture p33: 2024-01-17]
process/main/2024-01-15/20240115_Print1.jpeg

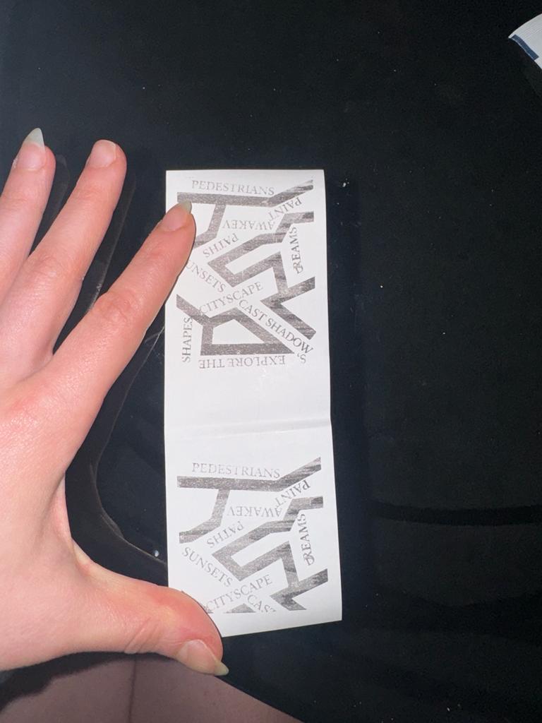
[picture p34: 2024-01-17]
process/main/2024-01-15/20240115_Print0.jpeg

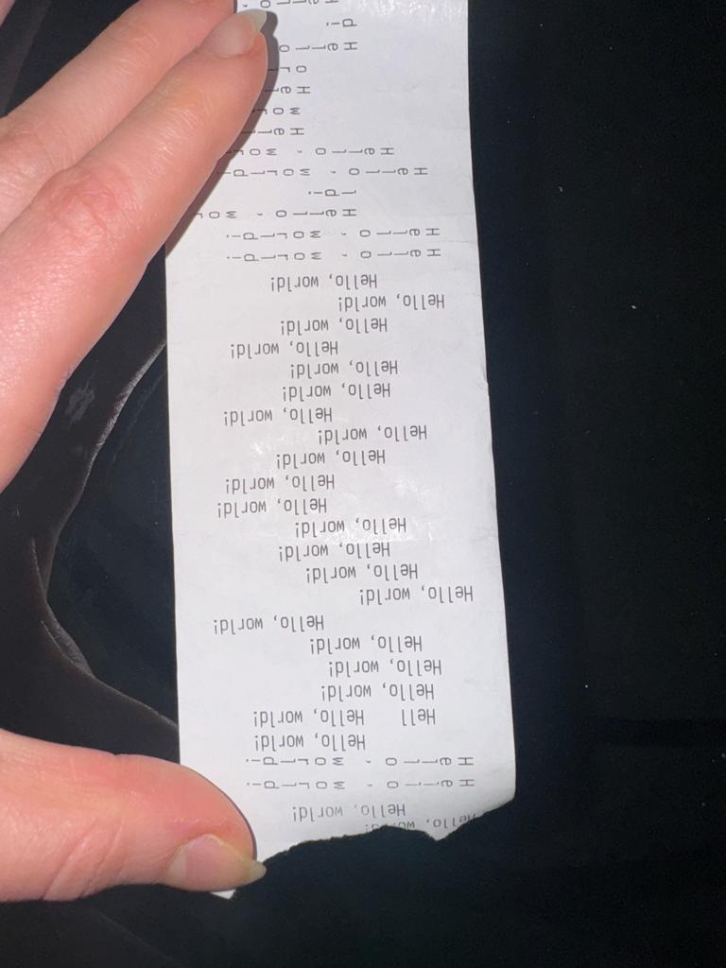
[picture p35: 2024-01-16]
process/main/2024-01-05/20241205_Print0.jpeg

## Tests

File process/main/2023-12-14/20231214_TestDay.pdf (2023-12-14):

move object | open object | recieve print

V1.1

V1.2

V1.3

V1.4

time:
mouvemtents:
complexity:
user observations:

archived:
time:
intuitivity
user observations:

time:
thoughts:
expectations

time:
mouvemtents:
complexity:
user observations:

archived:
time:
intuitivity
user observations:

time:
thoughts:

time:
mouvemtents:
complexity:
user observations:

archived:
time:
intuitivity:
user observations:

time:
thoughts:

time:
mouvemtents:
complexity:
user observations:

archived:
time:
intuitivity:
user observations:

time:
thoughts:

# Test day. V1

Observations on interactions on « John» V1. The goal is to define how intuitive the interaction is and help to develop the approptiate and the most user friendly product design.

## Storyboard

User insights
Observations
Descisions
(accelo or gps)
(hangable?)

move object | open object | recieve print

# Test day. V2

Observations on interactions with «John» V2. The aim is to define the portability of the real-size assistant. The amount of movement = GPS or accelerometer. Is it sufficiently comfortable and intuitive = to be portable in the bag in everyday life. Same design as V1 but daily life product destination.

## Storyboard

user observations:

User insights
Conclusions
Observations
Descisions
(I’m lost help me)

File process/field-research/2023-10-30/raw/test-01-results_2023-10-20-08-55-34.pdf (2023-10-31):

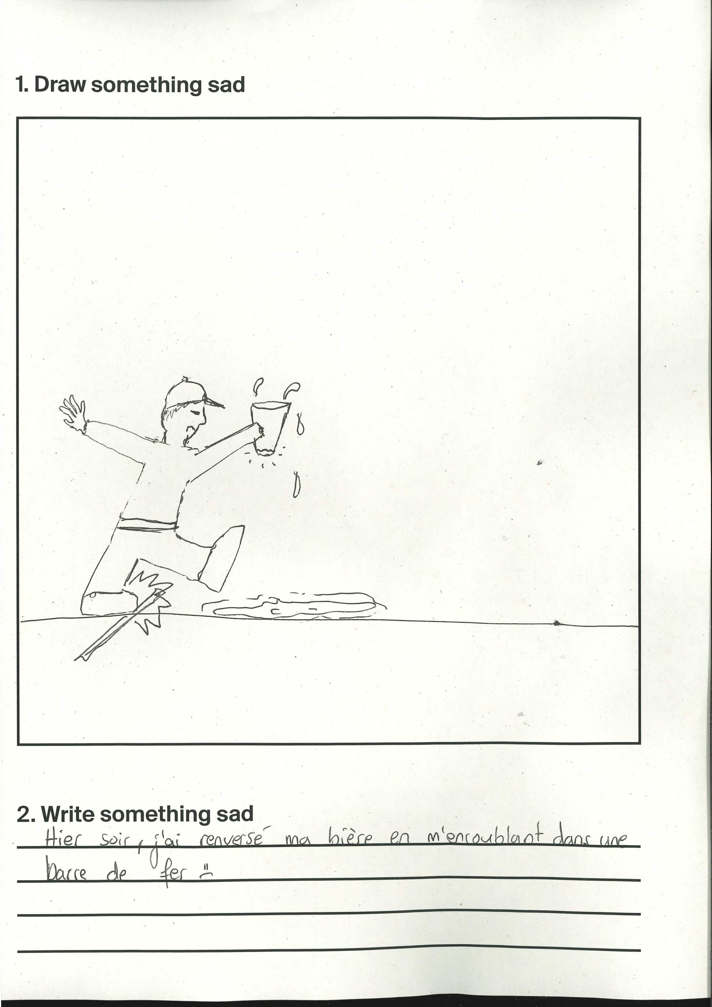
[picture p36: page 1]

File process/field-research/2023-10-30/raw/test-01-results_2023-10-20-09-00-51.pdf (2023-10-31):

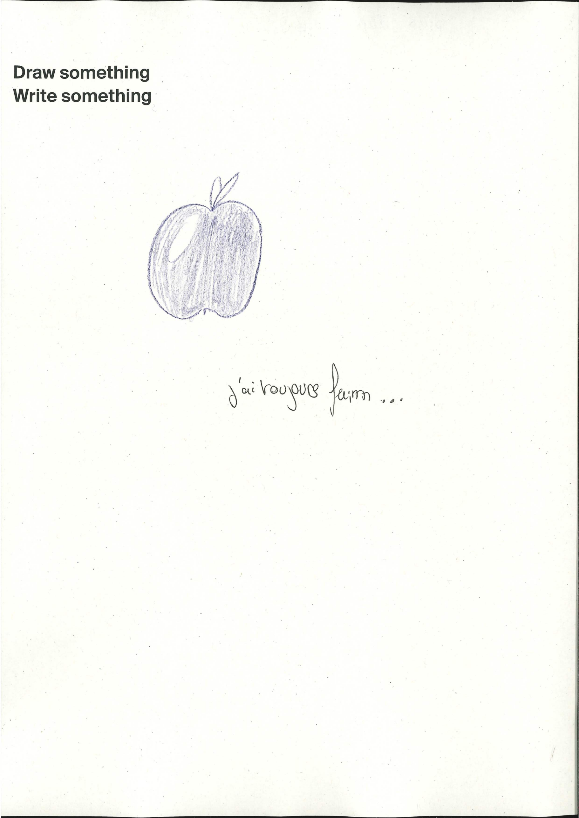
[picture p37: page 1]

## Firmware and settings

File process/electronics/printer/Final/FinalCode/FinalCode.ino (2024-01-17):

#include "Adafruit_Thermal.h"

#include "poem00.h"
#include "poem01.h"
#include "poem02.h"
#include "poem03.h"
#include "poem04.h"
#include "poem05.h"
#include "poem06.h"
#include "poem07.h"

#include "SoftwareSerial.h"
#define TX_PIN 11
#define RX_PIN 10

SoftwareSerial mySerial(RX_PIN, TX_PIN);  // Declare SoftwareSerial obj first
Adafruit_Thermal printer(&mySerial);      // Pass addr to printer constructor


#define poems_width 384
#define poems_height 550




void setup() {

  mySerial.begin(9600);  // Initialize SoftwareSeria

  printer.begin();  // Init printer (same regardless of serial type)

  // ajouter une ligne

  printer.println();

  // printer.feed(2);

  // //randomSeed(analogRead(0));
  // uint8_t index = random(1);  // le nombre de poemes
  // // en fonction de la valeur choisie aleatoirement
  // switch (index) {
  //   case 0:
  //     // imprimer ce poeme
  //     printer.printBitmap(poems_width, poems_height, poem07_data);
  //     break;  // fin des instructions
  //   // case 1:
  //   //   printer.printBitmap(poems_width, poems_height, poem01_data);
  //   //   break;
  //   // case 2:
  //   //   printer.printBitmap(poems_width, poems_height, poem02_data);
  //   //   break;
  //   // case 3:
  //   //   printer.printBitmap(poems_width, poems_height, poem03_data);
  //   //   break;
  //   // case 4:
  //   //   printer.printBitmap(poems_width, poems_height, poem04_data);
  //   //   break;
  //   // case 5:
  //   //   printer.printBitmap(poems_width, poems_height, poem05_data);
  //   //   break;
  //   // case 6:
  //   //   printer.printBitmap(poems_width, poems_height, poem06_data);
  //   //   break;
  //   // case 7:
  //   //   printer.printBitmap(poems_width, poems_height, poem07_data);
  //   //   break;
  //   default:
  //     break;
  // }


  printer.printBitmap(poems_width, poems_height, poem07_data);  //poem00 pour la demo




  // ajouter une ligne
  printer.println();

  // gros espace
  printer.feed(10);

  printer.sleep();       // Tell printer to sleep
  delay(3000L);          // Sleep for 3 seconds
  printer.wake();        // MUST wake() before printing again, even if reset
  printer.setDefault();  // Restore printer to defaults
}

void loop() {
}

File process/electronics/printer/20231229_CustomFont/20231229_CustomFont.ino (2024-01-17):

#include "Adafruit_Thermal.h"
#include "SoftwareSerial.h"

#define TX_PIN 5  // Arduino transmit YELLOW WIRE labeled RX on printer
#define RX_PIN 6  // Arduino receive GREEN WIRE labeled TX on printer

SoftwareSerial mySerial(RX_PIN, TX_PIN);  // Declare SoftwareSerial obj first
Adafruit_Thermal printer(&mySerial);      // Pass addr to printer constructor

void setup() {
  mySerial.begin(19200);  // Initialize SoftwareSerial
  printer.begin();        // Init printer
}

void loop() {
  // Print text with a custom font for lowercase 'a' (75x75 px)
  String text = "a";
  for (int i = 0; i < text.length(); i++) {
    printCustomCharacter(text[i]);
    delay(200);  // Adjust the delay as needed
  }
  printer.println();  // Move to the next line
  delay(200);         // Adjust the delay as needed
}

void printCustomCharacter(char c) {

  // Define a custom font for lowercase 'a' (75x75 px)
  const uint8_t customFont[][75] = {
    { // Define custom font for lowercase 'a'
      0xff, 0xff, 0xff, 0xff, 0xff, 0xff, 0xff, 0xff, 0xff, 0xe0, 0xff, 0xff, 0xff, 0xff, 0xff, 0xff,
      0xff, 0xff, 0xff, 0xe0, 0xff, 0xff, 0xff, 0xff, 0xff, 0xff, 0xff, 0xff, 0xff, 0xe0, 0xff, 0xff,
      0xff, 0xff, 0xff, 0xff, 0xff, 0xff, 0xff, 0xe0, 0xff, 0xff, 0xff, 0xff, 0xff, 0xff, 0xff, 0xff,
      0xff, 0xe0, 0xff, 0xff, 0xff, 0xff, 0xff, 0xff, 0xff, 0xff, 0xff, 0xe0, 0xff, 0xff, 0xff, 0xff,
      0xff, 0xff, 0xff, 0xff, 0xff, 0xe0, 0xff, 0xff, 0xff, 0xff, 0xff, 0xff, 0xff, 0xff, 0xff, 0xe0,
      0xff, 0xff, 0xff, 0xff, 0xff, 0xff, 0xff, 0xff, 0xff, 0xe0, 0xff, 0xff, 0xff, 0xff, 0xff, 0xff,
      0xff, 0xff, 0xff, 0xe0, 0xff, 0xff, 0xff, 0xff, 0xff, 0xff, 0xff, 0xff, 0xff, 0xe0, 0xff, 0xff,
      0xff, 0xff, 0xff, 0xff, 0xff, 0xff, 0xff, 0xe0, 0xff, 0xff, 0xff, 0xff, 0xff, 0xff, 0xff, 0xff,
      0xff, 0xe0, 0xff, 0xff, 0xff, 0xff, 0xff, 0xff, 0xff, 0xff, 0xff, 0xe0, 0xff, 0xff, 0xff, 0xff,
      0xff, 0xff, 0xff, 0xff, 0xff, 0xe0, 0xff, 0xff, 0xff, 0xff, 0xff, 0xff, 0xff, 0xff, 0xff, 0xe0,
      0xff, 0xff, 0xff, 0xff, 0xff, 0xff, 0xff, 0xff, 0xff, 0xe0, 0xff, 0xff, 0xff, 0xff, 0xff, 0xff,
      0xff, 0xff, 0xff, 0xe0, 0xff, 0xff, 0xff, 0xff, 0xff, 0xff, 0xff, 0xff, 0xff, 0xe0, 0xff, 0xff,
      0xff, 0xff, 0xff, 0xff, 0xff, 0xff, 0xff, 0xe0, 0xff, 0xff, 0xff, 0xff, 0xff, 0xff, 0xff, 0xff,
      0xff, 0xe0, 0xff, 0xff, 0xff, 0xff, 0xff, 0xff, 0xff, 0xff, 0xff, 0xe0, 0xff, 0xff, 0xff, 0xff,
      0xff, 0xff, 0xff, 0xff, 0xff, 0xe0, 0xff, 0xff, 0xff, 0xff, 0xff, 0xc3, 0xf8, 0x07, 0xff, 0xe0,
      0xff, 0xff, 0xff, 0xff, 0xfe, 0x1c, 0xf8, 0x07, 0xff, 0xe0, 0xff, 0xff, 0xff, 0xff, 0xf8, 0xff,
      0x70, 0x07, 0xff, 0xe0, 0xff, 0xff, 0xff, 0xff, 0xe3, 0xff, 0x30, 0x0f, 0xff, 0xe0, 0xff, 0xff,
      0xff, 0xff, 0xc7, 0xff, 0xb0, 0x0f, 0xff, 0xe0, 0xff, 0xff, 0xff, 0xff, 0x0f, 0xff, 0xa0, 0x1f,
      0xff, 0xe0, 0xff, 0xff, 0xff, 0xfe, 0x1f, 0xff, 0xa0, 0x1f, 0xff, 0xe0, 0xff, 0xff, 0xff, 0xfc,
      0x3f, 0xff, 0xa0, 0x1f, 0xff, 0xe0, 0xff, 0xff, 0xff, 0xf8, 0x7f, 0xff, 0x80, 0x3f, 0xff, 0xe0,
      0xff, 0xff, 0xff, 0xf0, 0x7f, 0xff, 0x80, 0x3f, 0xff, 0xe0, 0xff, 0xff, 0xff, 0xe0, 0xff, 0xff,
      0x80, 0x3f, 0xff, 0xe0, 0xff, 0xff, 0xff, 0xc1, 0xff, 0xff, 0x80, 0x7f, 0xff, 0xe0, 0xff, 0xff,
      0xff, 0x81, 0xff, 0xff, 0x00, 0x7f, 0xff, 0xe0, 0xff, 0xff, 0xff, 0x03, 0xff, 0xff, 0x00, 0xff,
      0xff, 0xe0, 0xff, 0xff, 0xfe, 0x03, 0xff, 0xff, 0x00, 0xff, 0xff, 0xe0, 0xff, 0xff, 0xfe, 0x07,
      0xff, 0xfe, 0x00, 0xff, 0xff, 0xe0, 0xff, 0xff, 0xfc, 0x07, 0xff, 0xfe, 0x01, 0xff, 0xff, 0xe0,
      0xff, 0xff, 0xf8, 0x0f, 0xff, 0xfe, 0x01, 0xff, 0xff, 0xe0, 0xff, 0xff, 0xf8, 0x0f, 0xff, 0xfc,
      0x01, 0xff, 0xff, 0xe0, 0xff, 0xff, 0xf0, 0x1f, 0xff, 0xfc, 0x03, 0xff, 0xff, 0xe0, 0xff, 0xff,
      0xe0, 0x1f, 0xff, 0xfc, 0x03, 0xff, 0xff, 0xe0, 0xff, 0xff, 0xe0, 0x3f, 0xff, 0xf8, 0x07, 0xff,
      0xff, 0xe0, 0xff, 0xff, 0xc0, 0x3f, 0xff, 0xf8, 0x07, 0xff, 0xff, 0xe0, 0xff, 0xff, 0xc0, 0x3f,
      0xff, 0xf0, 0x07, 0xff, 0xff, 0xe0, 0xff, 0xff, 0x80, 0x7f, 0xff, 0xf0, 0x0f, 0xff, 0xff, 0xe0,
      0xff, 0xff, 0x80, 0x7f, 0xff, 0xe0, 0x0f, 0xff, 0xff, 0xe0, 0xff, 0xff, 0x00, 0x7f, 0xff, 0xe0,
      0x0f, 0xff, 0xff, 0xe0, 0xff, 0xff, 0x00, 0x7f, 0xff, 0xc0, 0x1f, 0xff, 0xff, 0xe0, 0xff, 0xfe,
      0x00, 0xff, 0xff, 0xc0, 0x1f, 0xff, 0xff, 0xe0, 0xff, 0xfe, 0x00, 0xff, 0xff, 0xa0, 0x1f, 0xff,
      0xff, 0xe0, 0xff, 0xfe, 0x00, 0xff, 0xff, 0x80, 0x3f, 0xff, 0xff, 0xe0, 0xff, 0xfc, 0x00, 0xff,
      0xff, 0x40, 0x3f, 0xff, 0xff, 0xe0, 0xff, 0xfc, 0x00, 0xff, 0xfe, 0x40, 0x7f, 0xff, 0xff, 0xe0,
      0xff, 0xfc, 0x01, 0xff, 0xfe, 0x80, 0x7f, 0xff, 0xff, 0xe0, 0xff, 0xf8, 0x01, 0xff, 0xfd, 0x80,
      0x7f, 0xef, 0xff, 0xe0, 0xff, 0xf8, 0x01, 0xff, 0xf9, 0x00, 0xff, 0xcf, 0xff, 0xe0, 0xff, 0xf8,
      0x01, 0xff, 0xfb, 0x00, 0xff, 0xdf, 0xff, 0xe0, 0xff, 0xf8, 0x01, 0xff, 0xf7, 0x00, 0xff, 0xbf,
      0xff, 0xe0, 0xff, 0xf8, 0x01, 0xff, 0xe6, 0x01, 0xff, 0x3f, 0xff, 0xe0, 0xff, 0xf8, 0x01, 0xff,
      0xee, 0x01, 0xff, 0x7f, 0xff, 0xe0, 0xff, 0xf8, 0x01, 0xff, 0xdc, 0x03, 0xfe, 0xff, 0xff, 0xe0,
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

  // Map ASCII values to indices in the custom font
  int index = c - 'a';
  if (index >= 0 && index < 26) {
    printer.printBitmap(75, 75, customFont[index]);
  } else {
    // If the character is not in the custom font, print a space
    printer.printBitmap(75, 75, (uint8_t*)"                                      "
                                          "                                      "
                                          "                                      "
                                          "                                      "
                                          "                                      "
                                          "                                      "
                                          "                                      "
                                          "                                      "
                                          "                                      "
                                          "                                      ");
  }
}

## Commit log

2023-11-03 info added in prototypes
2023-12-19 files added
    [John_AlmostFinal.f3d]
2023-12-30 corrections in folders
    [John_AlmostFinal.f3d]
2024-01-16 info added to main
    [20240801_TheSet.f3d, fixed_03.f3d, fixed_03.stl]
2024-01-17 info added to maiin
    [20240116_Cover.stl, Ekaterina_Bliznyuk_Final.f3d]
